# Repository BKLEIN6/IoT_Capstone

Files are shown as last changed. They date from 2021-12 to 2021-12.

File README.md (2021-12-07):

#IoT Bootcamp Capstone

Overview
The purpose of this capstone is to be able to create a portable mesh network that can be deployed as needed in areas with minimal or no Cell signal. This version of the mesh network will be able to have a remote unit find it's GPS location and send it to a Ground Station. There is a 3rd node that will automatically allow the two devices to connect and continue to communicate once they are out of range.
Details
The device will use the following components: 
**Particle Argon (qty 1) 
**Teensy 3.1 (qty 1)
**ElectroPeak 64x128 OLED screen (qty 2) 
**resistor (1) 220ohm  
 **LED(qty 1)
 **Adafruit - Ultimate GPS (qty 1)
 **Sparkfun - XBEE Explorer (qty 2) 
**Digi XBEE Pro 900HP Dev Kit (qty 1)
 **Momentary Push Button (qty 1)
 **Breadboard (qty 2)
**External USB Power Packs (qty 3)
The project will be completed in the following steps:

    Notebook - rough documentation of idea and flow chart
    Fritzing - A diagram
    Breadboard
    Coding

Summary
This project is a proof of concept for adding onto a former cohorts idea for their Search and Rescue product design. The purpose of this capstone is to show that a portable mesh network can be set up to transmit data over extensive areas where cellphone signal is lacking and other elements may prevent good signal transmission, such as geography and vegetation.
There are 3 components being made for this project.
1) GPS Remote - This is unit will capture live GPS data, convert it to an XBEE API frame,  and transmit it to a specifically addressed unit (Ground Station). This unit will not create a network and will have to automatically join a specific network.
2) Ground Station - This unit will receive the data from the GPS Remote. This unit will create a network for the GPS Remote and Mesh Node to join. This unit will deconstruct the API frame it received, display the GPS coordinates on an OLED, and sent this information to an Adafruit Dashboard.
3) Mesh Node - This unit will only have power and will not be controlled by an external micro-controller. This node will only have its settings changed to be a router. It will only forward/repeat frames received. It does not save data. This unit should automatically connect the GPS Remote and Ground Station once they are out of range of each other and the Mesh Node is placed in between them. 

My Hackster
https://www.hackster.io/bklein6/portable-mesh-network-fb0e50

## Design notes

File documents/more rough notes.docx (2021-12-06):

Have tried the basics of mesh near home.

Going out from the home until the unit stop sending data.

Go back to where it received data again and leave the connecting node.

Walk away from the node into the known dead area and keep sending data.

Verified that it does work at the very least.

Some issues with hardware design and incorporation have shown up. Trying to make things a bit smaller and more space efficient has not worked as well as I had hoped. Finding some products from Sparkfun that seemed to be perfect for what I wanted to have not ended up working out. Due to the limitation on time, these have been tested and abandoned to maintain some semblance of staying on track.

Adding in a battery to external power has not quite worked as well as I had hoped. There were some issues with testing and have abandoned them for the moment to continue to make more forward progress with overall concept.

Using another Sparkfun product to help minimize space that does work half defeats the purpose of using the XBEE as a low voltage radio because the separate board requires 5v instead of 3.3v due to the LEDs on it (they say that it can go down to 3.3v but don’t think it worked right), and they’re just terrible LEDS. The Dev board for XBEE works better and has a 3.3v battery port for external power. Need to test powering that directly from the teensy or argon

The pin size/layout for the XBEE has been somewhat problematic. Noncompatible size all around for breadboard. The Dev board can have compatible pins but ends up being to wise to set on a single wide breadboard.

Trying to add on RP-SMA edge board connectors for the XBEE has been problematic. It seems like I got one board to sort of work with it, but overall, with the time frame it probably won’t be something I’ll be able to investigate further and get working properly. I would think it’s a simple solder and it would work set up, but need to do more research

Teensy 3.1 xbee adapter

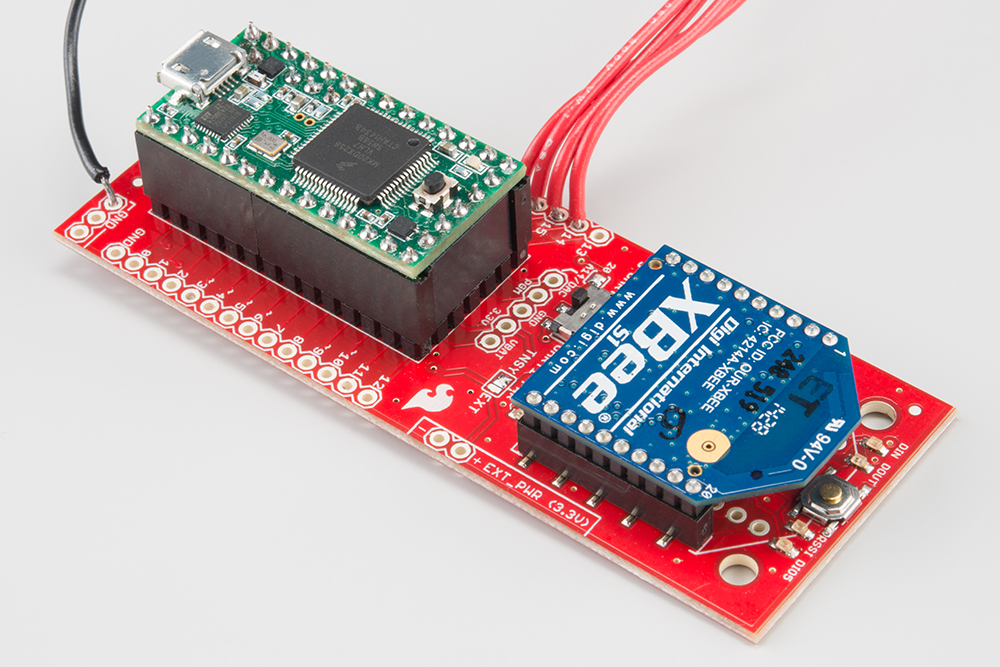
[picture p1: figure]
Teensy 3.1 XBee Adapter

Sparkfun xbee explorer regulated

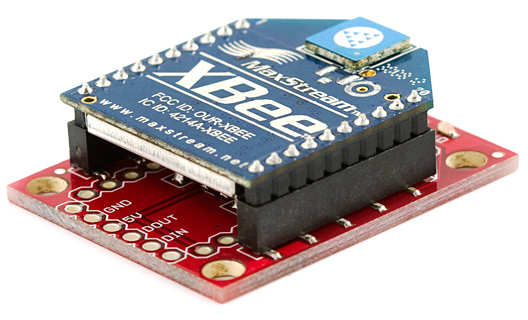
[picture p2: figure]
SparkFun XBee Explorer Regulated

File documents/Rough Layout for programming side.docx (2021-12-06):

1) Basic concept or idea – creating a portable mesh network for S&R
2) Find a product that looks usable, has what looks like decent number of recourses and has some repositories to use and roll with it.
3) Figure out how they work and how to set them up.
4) Figure out how to get them to communicate
  a. ended up testing in transparent mode and then API mode.
5) Get one radio to transmit anything from a teensy to a receiving unit.
  a. Able to get a teensy to count and send a signal in transparent mode every second or two to a receiver and have it print out the data. As I was able to prove that tx was possible, I did a small distance check around the school to see how far in line of sight and what would block the signal.
6) Get teensy to send an API packet to receiver and have it print out data.
  a. Created a packet in XCTU program, put that into a buffer to send. Ended up manually adding “0x##, ” to all values in buffer to get it to send.
  b. Now needed to get specific data in the packet – had to set up GPS.
7) Set up GPS on teensy and figured out basic setting to see data (repository was good and worked with minimal troubleshooting)
8) Set up OLED so I can print data to it and see what’s being printed out.
9) Getting values from the GPS, put those into the XCTU API frame generator.
  a. Manually created a new packet in teensy
10) Verified packet could be received with the specific data.
11) Set up Argon to receive data.
  a. Tried to use repository but could not get it to work.
  b. Ended up using a read if available, print data to buffer

if(Serial1.available()>0){

tempData[i] = Serial1.read();

Serial.printf(" %i 0x%X, ", i, tempData[i]);

i++;

12) An issue with incoming data
  a. Needed to put in a reset for the increment. If the increment went too far over the buffer, particle would reset and then increment would go back to 0.
13) Printed out buffer to make sure all data was copied over.
  a. Comparing to the original packet, found out of the data was missing or changed.
  b. Upon further inspection this is part of the addressing or packeting information before the actual data. The main data section was unchanged. Most of the information before and after was different.
14) After finding this out, needed to figure out a way to isolate just the data
  a. The issue would be that the packet will be a different size than the original and that the data can vary both potentially in size and location.
  b. Thought about removing excessive into such as removing the decimal. Found a function that prints just numbers with no decimal. “latitude_fixed” // fixed lat is 350844096 // fixed long is -1066463296.
15) Delineate latitude and longitude.
  a. Chose pipes for delineating lat and long from the rest of data. //buf is |350844096|-1066463296|.
16) Search for these specific characters and strip data from there
  a. Xbee library did not work – manual search and strip
  b. How do you search for a specific character and extract the data?

void findPipe(){

const char P_LEN = 5;

char pipe[P_LEN];

uint8_t i,p, latSize, lonSize;

char lat[15], lon[15];

p=0;

// Serial.printf("Chekcing for data");

if (tempData[0] != 0x7E){

Serial.printf("No Data, leaving function\n");

return;

}

Serial.printf("Start finding pipes");

for (i=0; i<BUF_LEN; i++){

if (tempData[i] == 0x7C){

pipe[p] = i;

Serial.printf("| at tempData[%i], pipe[%i] = %i\n", i, p, i);

p++;

}

}

latSize = pipe[1]-pipe[0]-1;

lonSize = pipe[2]-pipe[1]-1;

Serial.printf("latSize = %i lonSize = %i\n", latSize, lonSize);

memcpy(lat, &tempData[pipe[0]+1], latSize);

memcpy(lon, &tempData[pipe[1]+1], lonSize);

actualLat = atoi((char *)lat)/10000000.0;

actualLon = atoi((char *)lon)/10000000.0;

Serial.printf("Actual Lat = %f\n Actual Lon = %f\n", actualLat, actualLon);

17) After extracting the data and creating floats, now we need to use live data.
  a. At this point we need to make sure we’re able to create API packets with live GPS data.
  b. Found a library that had a partially written out packet create and check sum.
  c. Following their setup as a guide and referencing the API data sheet for xbee, I found a few issues. I was having some Checksum issues due to Part of their creating the packet setup.
  d. “txBuf[2] = sizeof(txBuf) + 14;” //LSB - Packet created with no additional data show 0E in XCTU so needs size of () + 14.

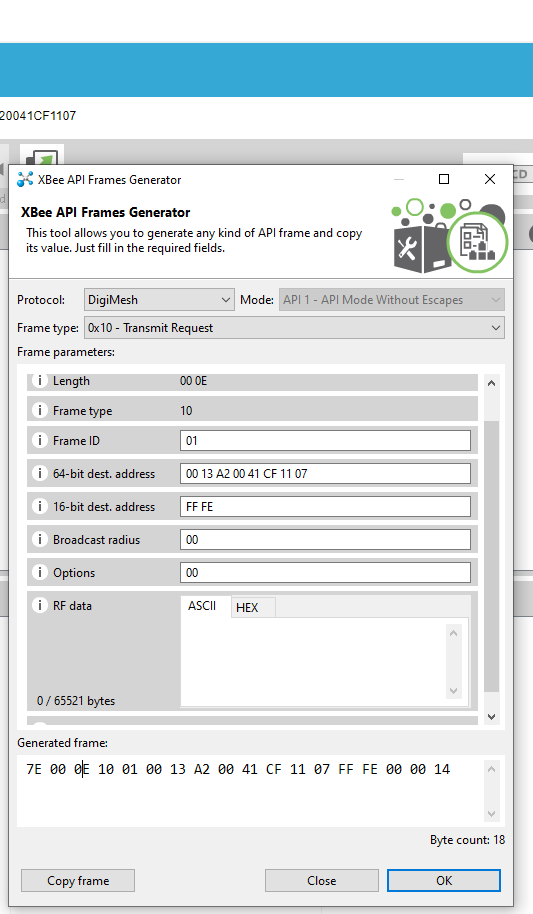
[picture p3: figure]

  e. Double checking their input looked correct, but I was still getting bad checksum numbers and the receiving unit wouldn’t accept the packet.
  f. Putting the new buffer into the XCTU software and seeing what their checksum number was compared to mine, it was a difference of 18.
  g. Removing the 14 to that specific part brought down the difference to 4. The new input for txBuf[2] would be sizeof(txBuf) – 4.
  h. Checksum is now correct and receiver accepts packets.
18) turn them into JSON buffers to send to a dashboard
19) Create Adafruit IO feed and dashboard.
20) Setup connection
21) Verify data sends and shows up in feed and dashboard
22) Remove button and auto send to dashboard
  a. After removing the button, an issue of how the data was being received and put into a buffer come up.
  b. Setting as a while statement and setting “i=0” after still set the buffer to always use position [0].

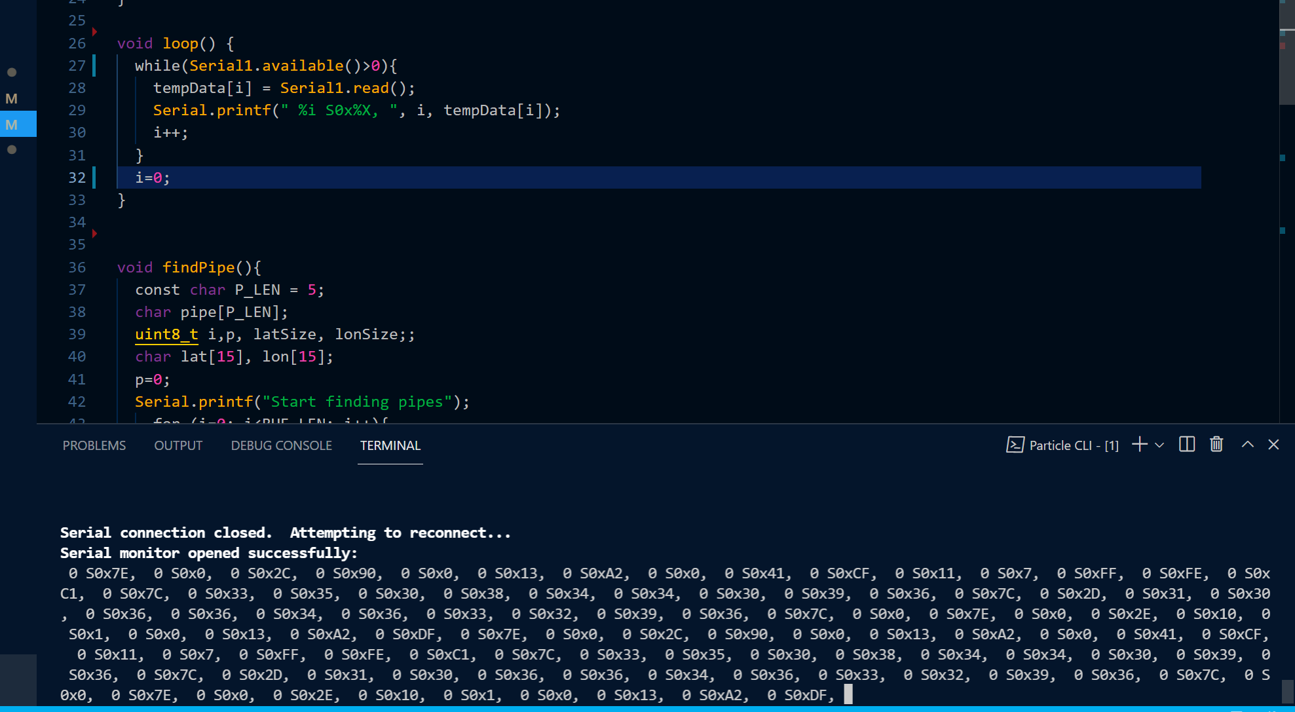
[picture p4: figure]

  c. Setting it as an if else statement ended up working. Apparently available cycles between 1 and 0 for each segment of data.

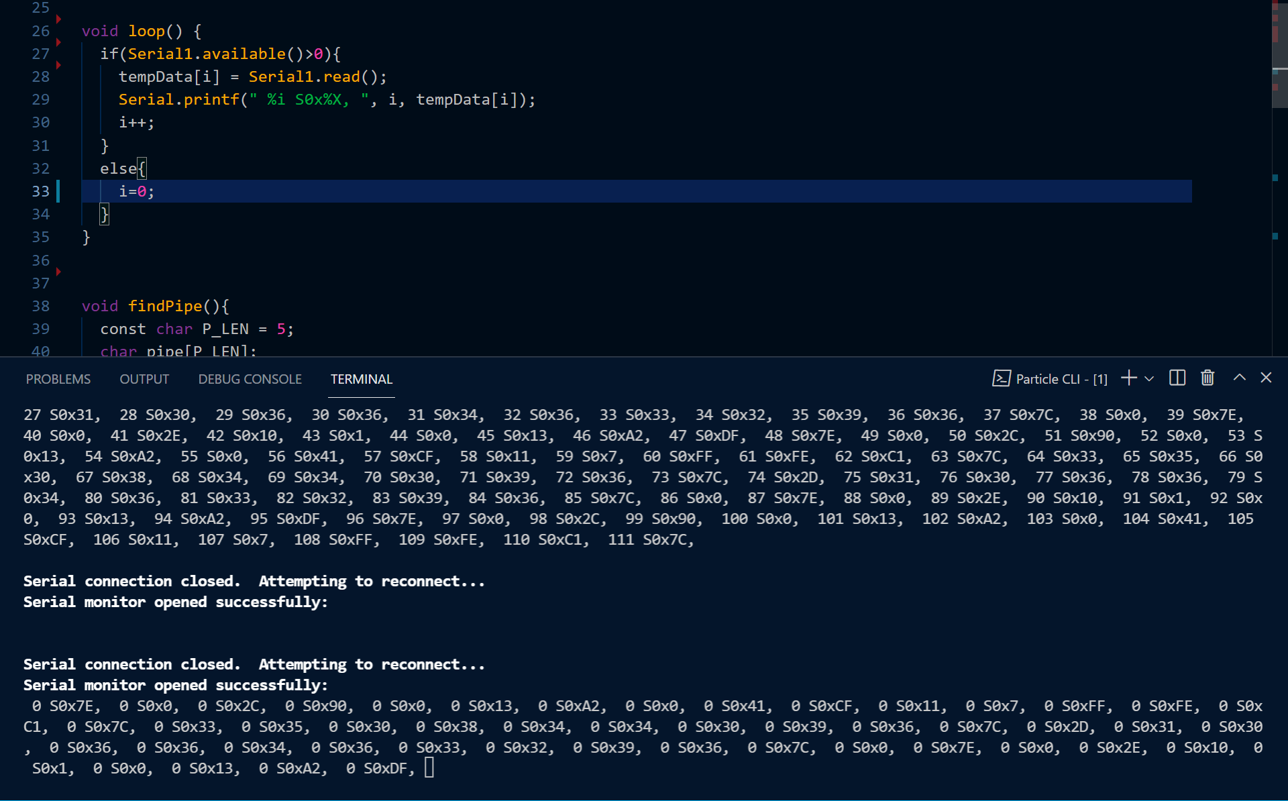
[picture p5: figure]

  d. Now we need to have a way for it to auto extract and send, but only there’s actual data that’s come in.

if(Serial1.available() == 0 && millis()-timerDelay >= 500){

i=0;

findPipe();

}

  e. Adding in the 500 millis() timer allows the cycle that happens when data comes in to not accidently be cut off early. A packet on average takes 500 millis() for all the data to be received and printed.
23) Now that it auto runs findPipe until data come in, we now have a flooding issue for the Dashboard. Putting in a check for the pack delimiter 7E or ASCII “ ~ “, we are able to prevent the function from continuing and flooding.

// Serial.printf("Chekcing for data");

if (tempData[0] != 0x7E){

// Serial.printf("No Data, leaving function\n");

return;

}

24) With everything working as expected one last issue came up. If the MQTT protocol doesn’t send/receive data after around 2 minutes, it will close the connection.
  a. Added a pinging function to ensure this does not happen.
25) The program works as intended, only sending GPS data to a dashboard when it received a verified pack.

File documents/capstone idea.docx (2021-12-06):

I want to make a GPS mesh network that uses an individual transmitter, a drone that acts as a connection point and a ground station. The idea would be to have an emergency GPS transmitter that can be dropped off out where S&R think someone will find it and be able to send their location.

If the location for the transmitter is too far away or has too much interference with trees, boulder, etc., there will be a drone that is modified to be a connection point between where the command center is and the GPS transmitter.

The modified drone will have solar panels on it to help extend flight time. (The hope is to get sufficient solar power on the drone so that during daylight hours, there will be no battery usage, the battery will be charged, and will have sufficient power at sunset/night to be able to return safely back to base). The point of this is to ensure that the drone can fly around a designated point to ensure that both the transmitter and control station will be able to communicate.

3 separate devices:

Ground Station (hooked up to computer)

Drone mesh

GPS transmitter

BASE COMPONENTS

Particle Argon (https://docs.particle.io/datasheets/wi-fi/argon-datasheet/) – base station and dashboard.

Teensy 3.1 (https://www.pjrc.com/teensy/teensy31.html) – Possibly needed for Drone and transmitting device.

Xbee 900hp (https://www.mouser.com/datasheet/2/111/ds-xbee-900hp-digimesh-kit-1374862.pdf) – digiMesh. Should have sufficient range to transmit (need to look into getting better antenna mounts/antenna to extend range).

Adafruit GPS (https://www.mouser.com/datasheet/2/737/adafruit_ultimate_gps-779243.pdf) – Needed for transmitting device.

ZOHD Talon GT Rebel (https://www.zohd.net/zohd-talon-gt-rebel) – best I can do without waiting a year or paying double for a used flying wing. Would prefer something with more wing surface area. Also have to worry a bit about fuselage dimensions with prebuilt.

Pixhawk The Orange Cube (https://ardupilot.org/copter/docs/common-thecubeorange-overview.html) – allows for planning missions, live time setting loiter mode position, real time telemetry updates.

Stage 1: Verify I can talk to all 3 xbee components, get them to connect to each other

Stage 2: Verify I can transmit anything amongst them, see if I can force a jump from device 1 to device to and have device 2 forward to device 3.

Stage 3: Add GPS data.

Stage 4: Test range.

Stage 5: Build case for transmitter, ground station, figure out drone wiring.

Stage 6: Get drone working.

Stage 7: Field test.

Stage 8: Forget to record videos for all stages, panic, make videos, make a video for capstone.

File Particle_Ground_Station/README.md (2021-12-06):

# Particle_Ground_Station

A Particle project named Particle_Ground_Station

## Welcome to your project!

Every new Particle project is composed of 3 important elements that you'll see have been created in your project directory for Particle_Ground_Station.

#### ```/src``` folder:  
This is the source folder that contains the firmware files for your project. It should *not* be renamed. 
Anything that is in this folder when you compile your project will be sent to our compile service and compiled into a firmware binary for the Particle device that you have targeted.

If your application contains multiple files, they should all be included in the `src` folder. If your firmware depends on Particle libraries, those dependencies are specified in the `project.properties` file referenced below.

#### ```.ino``` file:
This file is the firmware that will run as the primary application on your Particle device. It contains a `setup()` and `loop()` function, and can be written in Wiring or C/C++. For more information about using the Particle firmware API to create firmware for your Particle device, refer to the [Firmware Reference](https://docs.particle.io/reference/firmware/) section of the Particle documentation.

#### ```project.properties``` file:  
This is the file that specifies the name and version number of the libraries that your project depends on. Dependencies are added automatically to your `project.properties` file when you add a library to a project using the `particle library add` command in the CLI or add a library in the Desktop IDE.

## Adding additional files to your project

#### Projects with multiple sources
If you would like add additional files to your application, they should be added to the `/src` folder. All files in the `/src` folder will be sent to the Particle Cloud to produce a compiled binary.

#### Projects with external libraries
If your project includes a library that has not been registered in the Particle libraries system, you should create a new folder named `/lib/<libraryname>/src` under `/<project dir>` and add the `.h`, `.cpp` & `library.properties` files for your library there. Read the [Firmware Libraries guide](https://docs.particle.io/guide/tools-and-features/libraries/) for more details on how to develop libraries. Note that all contents of the `/lib` folder and subfolders will also be sent to the Cloud for compilation.

## Compiling your project

When you're ready to compile your project, make sure you have the correct Particle device target selected and run `particle compile <platform>` in the CLI or click the Compile button in the Desktop IDE. The following files in your project folder will be sent to the compile service:

- Everything in the `/src` folder, including your `.ino` application file
- The `project.properties` file for your project
- Any libraries stored under `lib/<libraryname>/src`

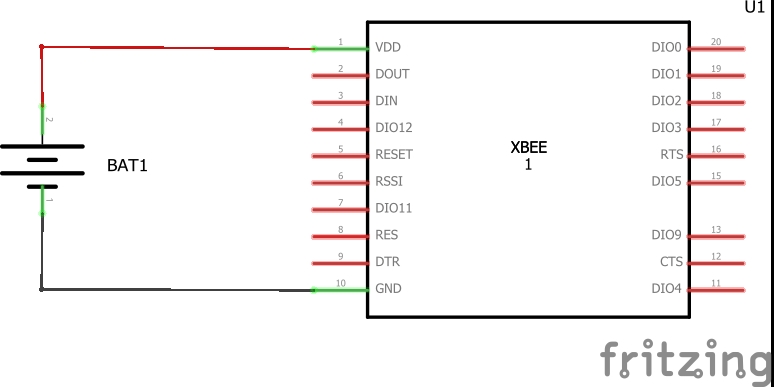
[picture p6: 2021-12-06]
documents/drone node_schem.jpg

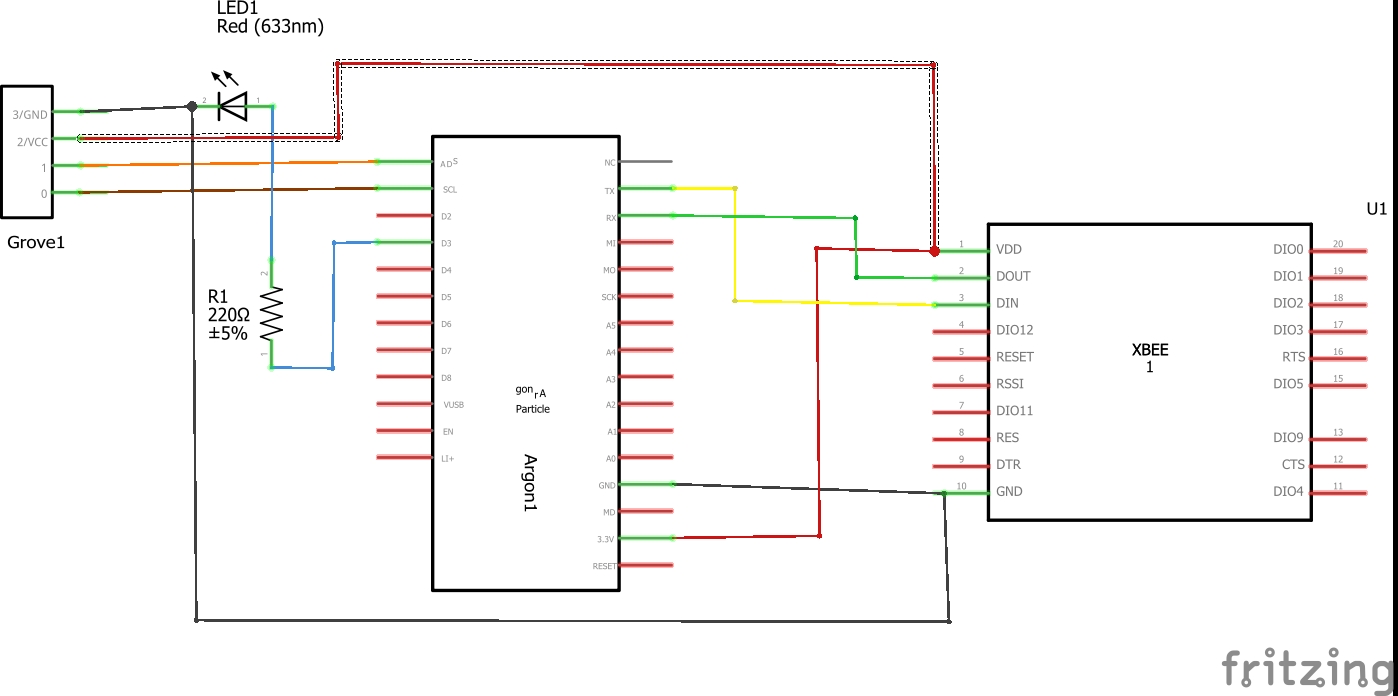
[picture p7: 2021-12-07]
documents/Ground Station Module_schem.jpg

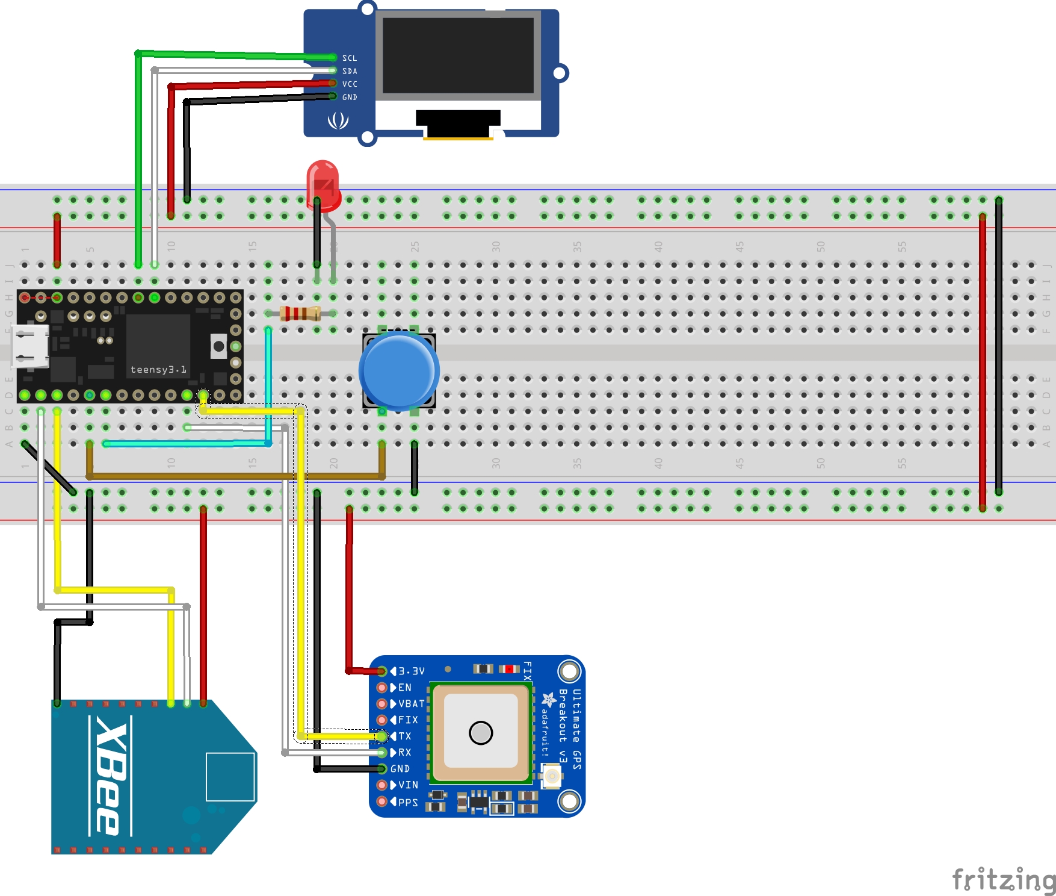
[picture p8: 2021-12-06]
documents/GPS Module_bb.jpg

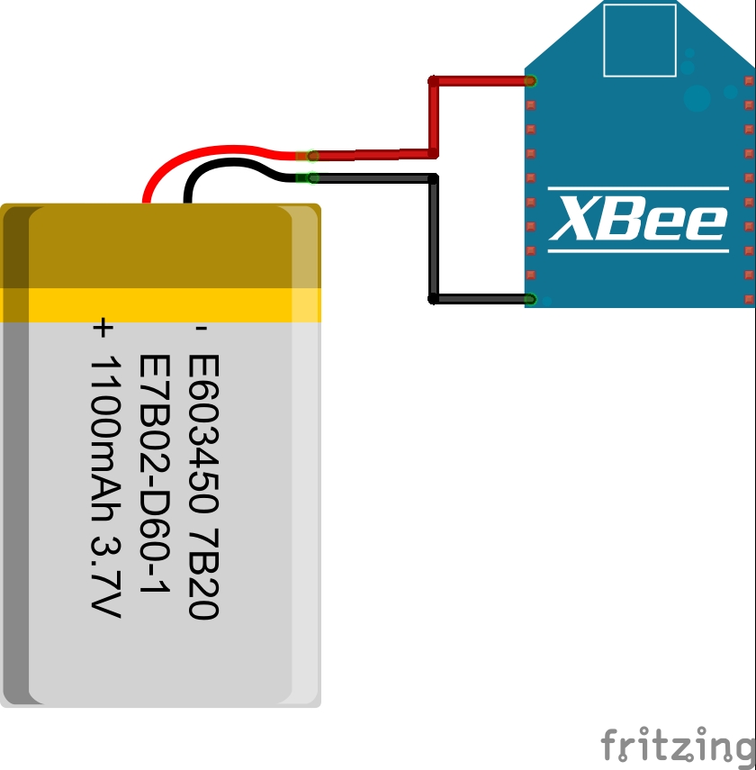
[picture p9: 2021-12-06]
documents/drone node_bb.jpg

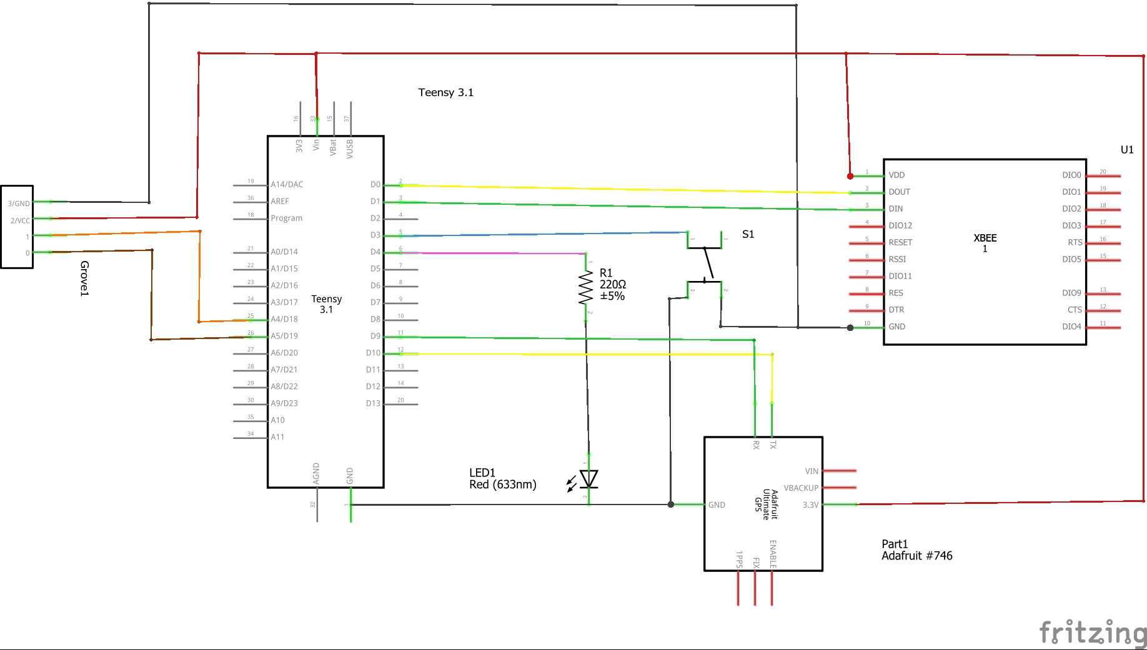
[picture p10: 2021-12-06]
documents/GPS Module_schem.jpg

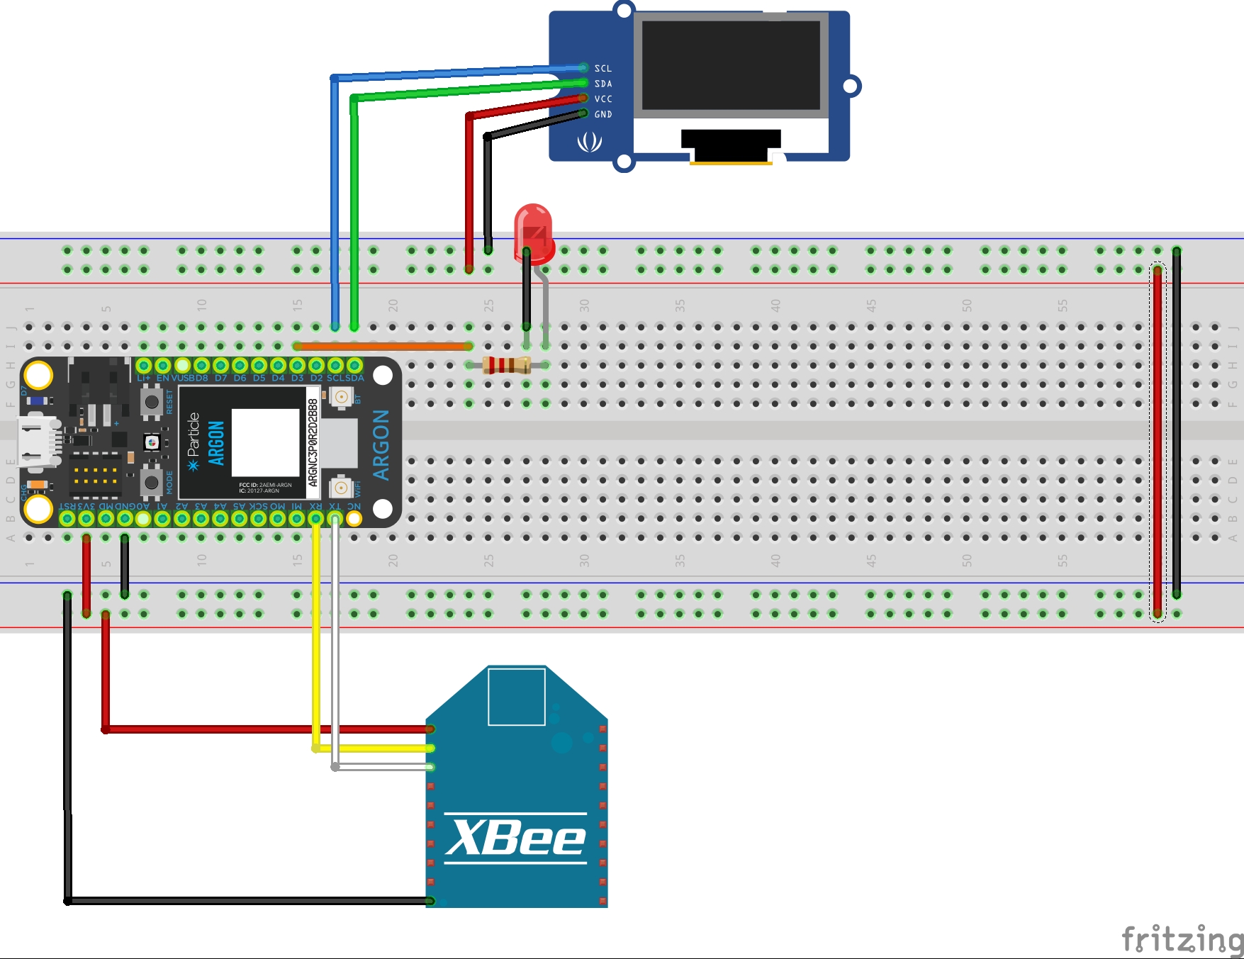
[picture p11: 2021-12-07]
documents/Ground Station Module_bb.jpg

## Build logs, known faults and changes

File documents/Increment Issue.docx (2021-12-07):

Increment reset issue

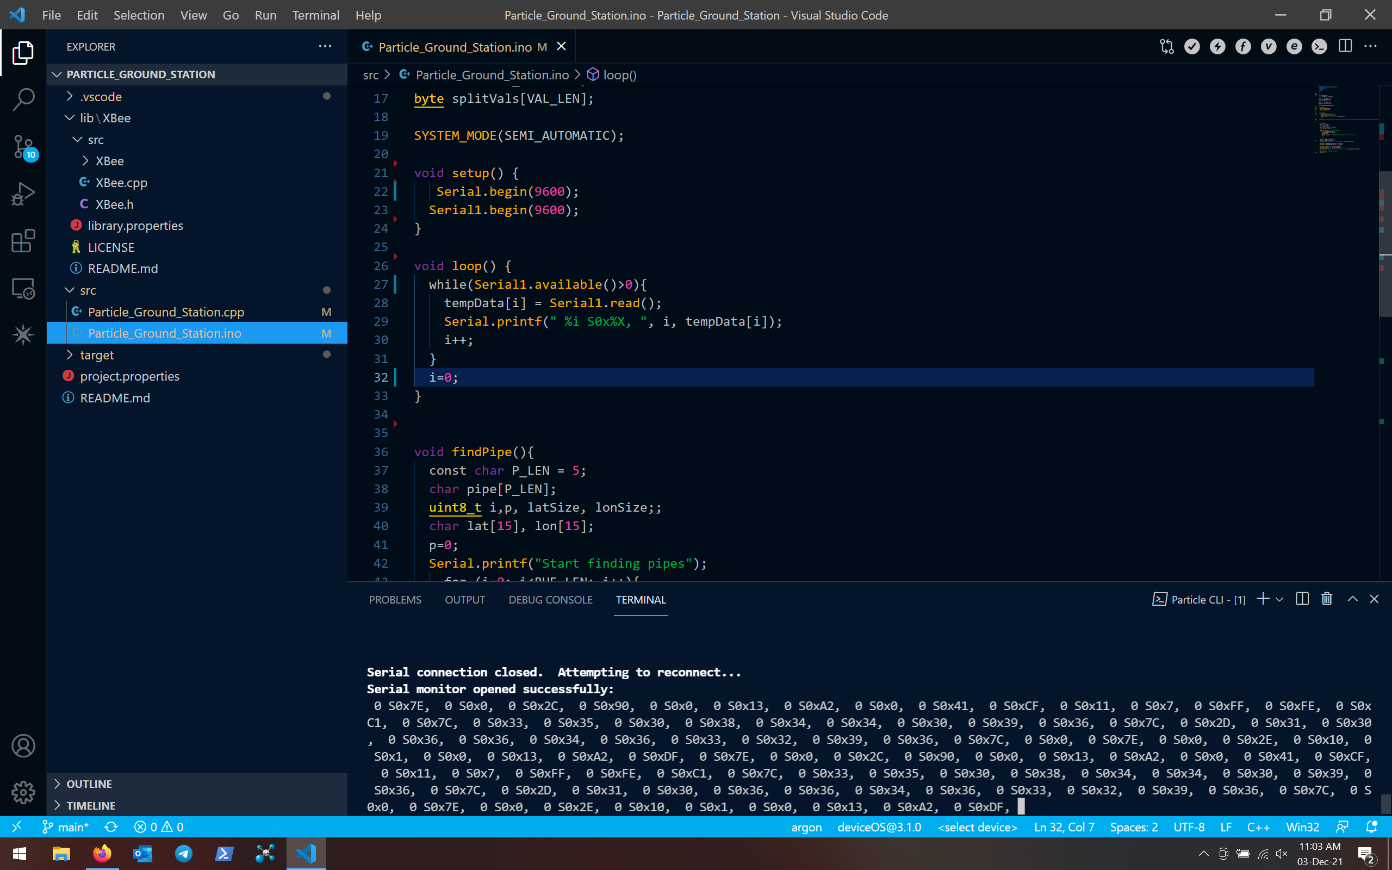
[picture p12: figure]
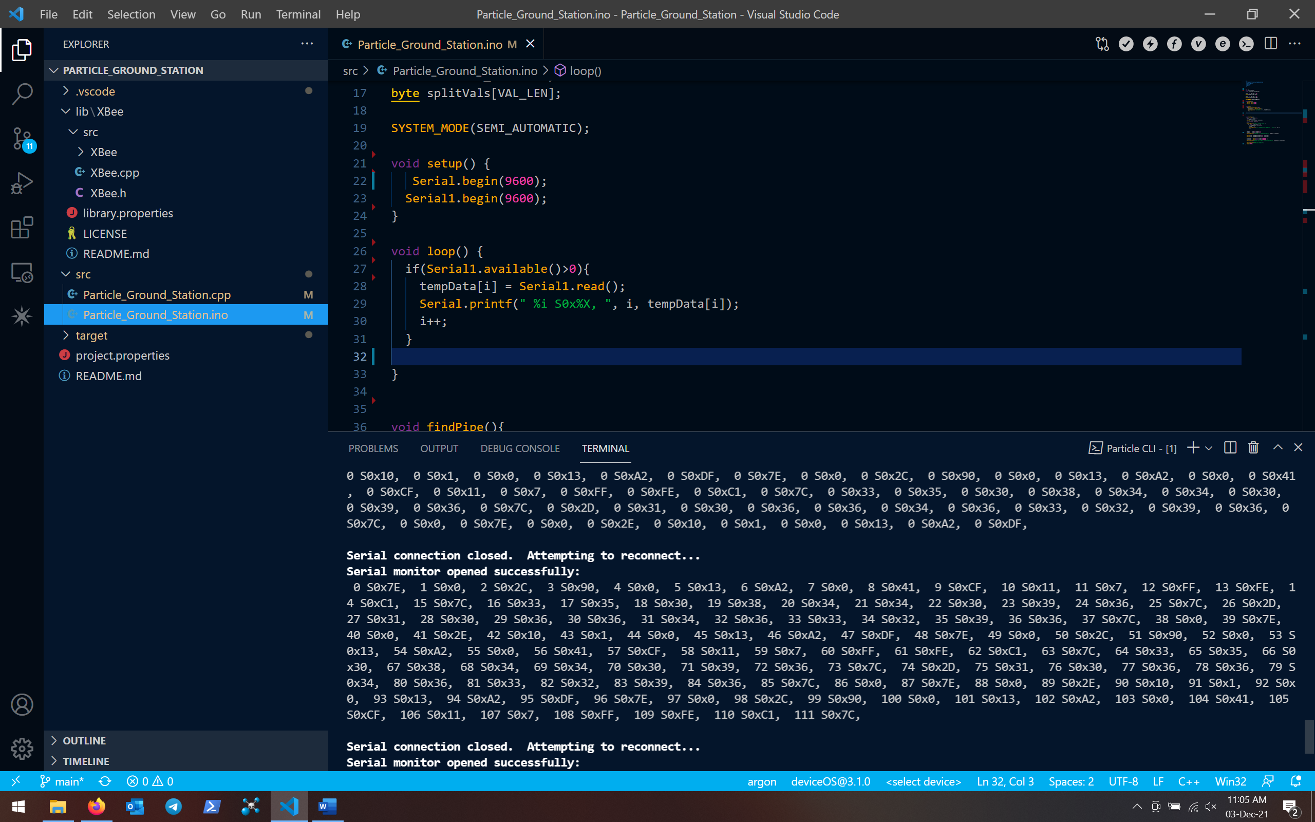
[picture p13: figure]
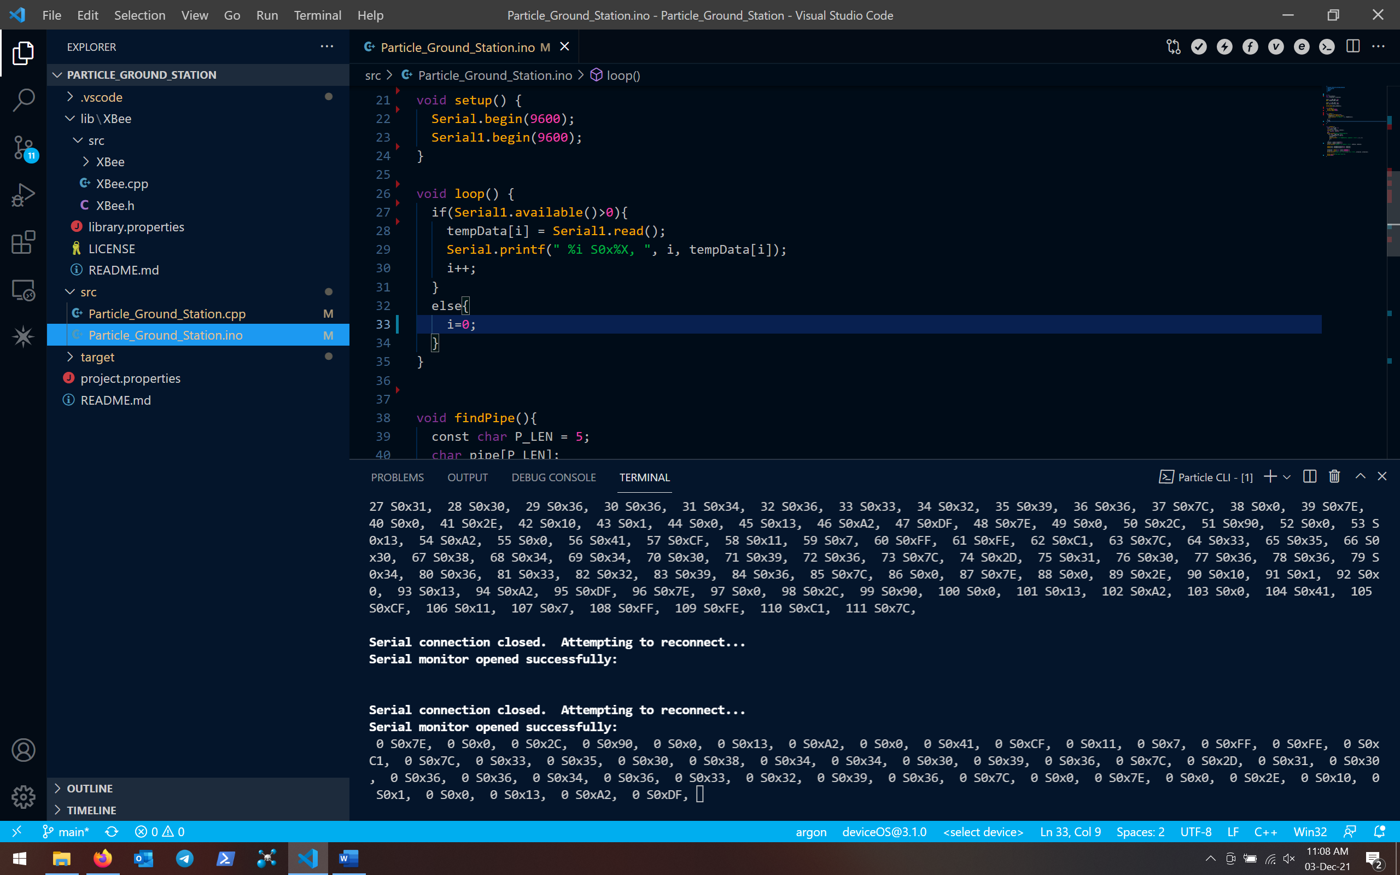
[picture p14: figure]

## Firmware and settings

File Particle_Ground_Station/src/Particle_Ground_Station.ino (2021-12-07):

/*
 * Project Particle_Ground_Station
 * Description: Gound Station for receiving GPS data and posting to a Dashboard
 * Author:Ben Klein
 * Date:05-Dec-2021
 */

//Adafruit dashboard setup
#include <Adafruit_MQTT.h>
#include "Adafruit_MQTT/Adafruit_MQTT.h" 
#include "Adafruit_MQTT/Adafruit_MQTT_SPARK.h" 
#include "credentials.h"
#include "JsonParserGeneratorRK.h" //this must be above OLED setup -- errors abound if not

//OLED
#include "Adafruit_GFX.h"
#include "Adafruit_SSD1306.h"

#define OLED_RESET D4
Adafruit_SSD1306 display(OLED_RESET);

const int LED = D3;
int i, timerDelay, last; 
bool switchState;

const int BUF_LEN = 50;
byte tempData[BUF_LEN];

TCPClient TheClient; 

Adafruit_MQTT_SPARK mqtt(&TheClient,AIO_SERVER,AIO_SERVERPORT,AIO_USERNAME,AIO_KEY);

/****************************** Feeds ***************************************/ 
// Setup Feeds to publish or subscribe 
// MQTT paths for AIO follow the form: <username>/feeds/<feedname> 
Adafruit_MQTT_Publish gpsObj1 = Adafruit_MQTT_Publish(&mqtt, AIO_USERNAME "/feeds/GPS");

SYSTEM_MODE(SEMI_AUTOMATIC);

void setup() {
  Serial.begin(9600);
  Serial1.begin(9600);
  pinMode(LED, OUTPUT);
  timerDelay = millis();
  last = millis();

//OLED setup
display.begin(SSD1306_SWITCHCAPVCC, 0x3C);  
display.display(); // show splashscreen
delay(2000);
display.clearDisplay();// clears splashscreen 
display.display();


   //Connect to WiFi without going to Particle Cloud
  // WiFi.connect();
  // while(WiFi.connecting()) {
  //   Serial.printf(".");
  // }
}

void loop() {
  // MQTT_connect(); 
  // MQTT_ping();
  if(Serial1.available()>0){
    digitalWrite(LED, HIGH);
    tempData[i] = Serial1.read();
    // Serial.printf(" %i 0x%X, ", i, tempData[i]);
    i++;
    timerDelay=millis();
  }
  if(Serial1.available() == 0 && millis()-timerDelay >= 500){
    i=0;
    digitalWrite(LED, LOW);
    findPipe();
  }
}

void findPipe(){  
  const char P_LEN = 5;
  char pipe[P_LEN], lat[15], lon[15];
  uint8_t i,p, latSize, lonSize;
  float actualLat, actualLon;
  p=0;
  // Serial.printf("Chekcing for data");
  if (tempData[0] != 0x7E){
    // Serial.printf("No Data, leaving function\n");
    return;
  }
  // Serial.printf("Start finding pipes");
  for (i=0; i<BUF_LEN; i++){
   if (tempData[i] == 0x7C){
      pipe[p] = i;
      // Serial.printf("| at tempData[%i], pipe[%i] = %i\n", i, p, i);
      p++;
      }
    }
  latSize = pipe[1]-pipe[0]-1;
  lonSize = pipe[2]-pipe[1]-1;
  // Serial.printf("latSize = %i lonSize = %i\n", latSize, lonSize);

  memcpy(lat, &tempData[pipe[0]+1], latSize);
  memcpy(lon, &tempData[pipe[1]+1], lonSize);

  actualLat = atoi((char *)lat)/10000000.0;
  actualLon = atoi((char *)lon)/10000000.0;
  // Serial.printf("Actual Lat = %f\n Actual Lon = %f\n", actualLat, actualLon);
  // Serial.printf("End pipe find\n");

  //created json buffer to send to Adafruit IO dashboard.
  JsonWriterStatic<256> jw;{
    JsonWriterAutoObject obj(&jw);
    jw.insertKeyValue("lat", actualLat);
    jw.insertKeyValue("lon", actualLon);
  }
  
  gpsObj1.publish(jw.getBuffer());

  //OLED display
  display.clearDisplay();
  display.setTextSize(1);
  display.setTextColor(WHITE);
  display.setCursor(0,0);
  display.printf("Received Coordinates: \n Lat: %f\n Lon: %f\n ", actualLat, actualLon);
  display.display();

  tempData[0] = 0;
}

// Function to connect and reconnect as necessary to the MQTT server.
void MQTT_connect() {
  int8_t ret;
 
  // Stop if already connected.
  if (mqtt.connected()) {
    return;
  }
 
  Serial.print("Connecting to MQTT... ");
 
  while ((ret = mqtt.connect()) != 0) { // connect will return 0 for connected
       Serial.printf("%s\n",(char *)mqtt.connectErrorString(ret));
       Serial.printf("Retrying MQTT connection in 5 seconds..\n");
       mqtt.disconnect();
       delay(5000);  // wait 5 seconds
  }
  Serial.printf("MQTT Connected!\n");
}

void MQTT_ping(){
  // Ping MQTT Broker every 2 minutes to keep connection alive
  if ((millis()-last)>120000) {
      Serial.printf("Pinging MQTT \n");
      if(! mqtt.ping()) {
        Serial.printf("Disconnecting \n");
        mqtt.disconnect();
      }
      last = millis();
  }
}

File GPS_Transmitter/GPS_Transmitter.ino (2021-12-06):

/*
   Projuect: Capstone GPS Transmitter
   Description: Sends GPS data to a Gound Station over XBEE wireless network
   Author: Ben Klein
   Date: 01-Dec-2021
*/

// OLED Setup
#include <SPI.h>
#include <Wire.h>
#include <Adafruit_GFX.h>
#include <Adafruit_SSD1306.h>

//Ultimate GPS Setup
#include <Adafruit_GPS.h>

// Name of the hardware serial port
#define GPSSerial Serial2

//OLED Settings
#define SCREEN_WIDTH 128
#define SCREEN_HEIGHT 64
#define SCREEN_ADDRESS 0x3C

// Connect to the GPS on the hardware port
Adafruit_GPS GPS(&GPSSerial);

// Set GPSECHO to 'false' to turn off echoing the GPS data to the Serial console
// Set to 'true' if you want to debug and listen to the raw GPS sentences
#define GPSECHO false

const int LED = 4;
const int BUTTON = 3;
int timer, buttonStatus;
bool sButtonStatus;

//Applying setting to OLED object
Adafruit_SSD1306 display(SCREEN_WIDTH, SCREEN_HEIGHT, &Wire); //creating object

void setup() {

  pinMode(LED, OUTPUT);
  pinMode(BUTTON, INPUT_PULLUP);
  sButtonStatus = false;
  buttonStatus = digitalRead(BUTTON);
  timer = millis();

  // connect at 115200 so we can read the GPS fast enough and echo without dropping chars
  Serial.begin(115200);
  //  while (!Serial);

  Serial1.begin(9600); //for XBEE

  attachInterrupt(BUTTON, sButton, RISING);

  // GPS SETUP
  // 9600 NMEA is the default baud rate for Adafruit MTK GPS's- some use 4800
  GPS.begin(9600); //Serial2
  // uncomment this line to turn on RMC (recommended minimum) and GGA (fix data) including altitude
  GPS.sendCommand(PMTK_SET_NMEA_OUTPUT_RMCGGA);
  // Set the update rate
  GPS.sendCommand(PMTK_SET_NMEA_UPDATE_1HZ); // 1 Hz update rate
  // For the parsing code to work nicely and have time to sort thru the data, and
  // print it out we don't suggest using anything higher than 1 Hz

  // Request updates on antenna status, comment out to keep quiet
  GPS.sendCommand(PGCMD_ANTENNA);
  delay(1000);
  // Ask for firmware version
  GPSSerial.println(PMTK_Q_RELEASE);

  //Starting OLED
  display.begin(SSD1306_SWITCHCAPVCC, SCREEN_ADDRESS);
  display.display();
  delay(2000);
  display.clearDisplay();
}

void loop() {
  gpsLoop();
  sendAttempt();
}

void gpsLoop() {
  // read data from the GPS in the 'main loop'
  char c = GPS.read();
  if (GPSECHO)
    if (c) Serial.print(c);
  // if a sentence is received, we can check the checksum, parse it...
  if (GPS.newNMEAreceived()) {
    if (!GPS.parse(GPS.lastNMEA())) // this also sets the newNMEAreceived() flag to false
      return; // we can fail to parse a sentence in which case we should just wait for another
  }

  // approximately every 2 seconds or so, print out the current stats
  if (millis() - timer > 2000) {
    timer = millis(); // reset the timer
    OLED();
  }
}

void sendAttempt() {
  if (sButtonStatus == true) {
    digitalWrite(LED, HIGH);
    delay(250);
    sButton();
    SOLED();
    packetSend();
  }
  else {
    //    Serial.printf("buttonState is %i\n", sButtonStatus);
    digitalWrite(LED, LOW);
  }
}

void sButton() {
  sButtonStatus = !sButtonStatus;
  Serial.printf("buttonState is %i\n", sButtonStatus);
}

//API frame creator and sender
void packetSend() {
  int i;
  uint8_t sum, tempChecksum, checksum;
  const int PAY_LEN = 30;
  byte payload[PAY_LEN];
  const int BUF_LEN = 40;
  byte txBuf[BUF_LEN]; // manual TX packet creation - 6-13 are 64-bit address

  sprintf((char *)payload, "|%i|%i|", GPS.latitude_fixed, GPS.longitude_fixed);

  txBuf[0] = 0x7E;    //start delimiter
  txBuf[1] = 0x00;    //MSB
  txBuf[2] = sizeof(txBuf) - 4; // LSB needed-4 to be added to make sure checksum values added up correctly
  txBuf[3] = 0x10; // API Frame type
  txBuf[4] = 0x01; //Frame ID
  txBuf[5] = 0x00; // start of 64-bit address
  txBuf[6] = 0x13;
  txBuf[7] = 0xA2;
  txBuf[8] = 0x00;
  txBuf[9] = 0x41;
  txBuf[10] = 0xCF;
  txBuf[11] = 0x10;
  txBuf[12] = 0x39;
  txBuf[13] = 0xFF; //MSB 16 bit address
  txBuf[14] = 0xFE; //LSB 16 bit address
  txBuf[15] = 0x00; //Broadcast Radius
  txBuf[16] = 0x00; //Options

  // This section puts the GPS data into the packet.
  for (i = 17; i < BUF_LEN; i++) {
    txBuf[i] = payload[i - 17];
  }

  // This section ceates the base for the checksum needed at the end of the packet
  sum = 0x00;
  for (i = 3; i < BUF_LEN - 1; i++) {
    sum = sum + txBuf[i];
  }

  // this created the checksum and puts it at the end of the frame
  checksum = 0xFF - sum;
  txBuf[BUF_LEN - 1] = checksum;
  Serial1.write(txBuf, sizeof(txBuf));
}

void OLED() {
  display.clearDisplay();
  display.setTextSize(1);
  display.setTextColor(SSD1306_WHITE);//inverse text
  display.setCursor(0, 10);
  display.setRotation(0);
  display.printf("Your location is: \n Lat: %f\n Lon: %f\n ", GPS.latitudeDegrees, GPS.longitudeDegrees);
  display.display();
}

void SOLED() {
  display.clearDisplay();
  display.setTextSize(1);
  display.setTextColor(SSD1306_WHITE);//inverse text
  display.setCursor(0, 10);
  display.setRotation(0);
  display.printf("Your location has\n been sent!\n Lat: %f\n Lon: %f\n ", GPS.latitudeDegrees, GPS.longitudeDegrees);
  display.display();
}

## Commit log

2021-12-06 fritzing added
    [GPS Module.fzz, Ground Station Module.fzz, drone node.fzz]
2021-12-06 clean up of code, start adding documentation
    [GPS Module.fzz, Ground Station Module.fzz, drone node.fzz]
2021-12-07 updated fritzing and GS code
    [Ground Station Module.fzz]
2021-12-07 documentation update
    [Ground Station Module.fzz]
